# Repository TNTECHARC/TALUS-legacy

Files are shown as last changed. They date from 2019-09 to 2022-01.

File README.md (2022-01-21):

# Talus
Totally Autonomous Legitimately Useful System

***

## Languages
- API is coded in ArduinoIDE (basically C++)

***

## Spring 2022 Goals
- 3D print all missing body parts
- Get a full set of working servos
- Improve API functionality
  ### Stretch Goals
  - Work in inverse kinematics
  - Implement a Raspberry PI for servo and voice control

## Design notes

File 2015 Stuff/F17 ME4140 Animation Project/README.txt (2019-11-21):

Deliverables from a final project in the Fall 2017 session of Tennessee Tech
course ME 4140 Intro to Robotics. The goals were:
1. Develope an animation of TALUS using the concepts of forward and inverse
   kinematics (discussed both in ME 4140 and ME 3610 Dynamics of Machinery).
2. Further the development of TALUS hardware systems

This folder contains:
- stlread.m: a function which reads STLs into a MATLAB script
- TALUS_Forward_12_12_17: an unfinished program to complete Goal 1
- TALUS_Forward_12_12_17_demo: the script used to generate the
  following animations.
- Joint_animation: MP4 showing full range of motion for several joints
- Wave_animation: MP4 demonstrating a wave
- TALUS_Dem: an arduino code used to replicate the animate motions on the real robot
- Joint_demo: video of hardware system replicating corresponding animation
- Wave_demo: video of hardware system replicating corresponding animation

Also included are STLs of each rigid body on TALUS made by assembling the
individual part STLs found on the websites. This process required loading them
into Inventor with Mesh Enabler.

This project is by no means complete, as only a portion of the right arm is
functional (F2017). Reccomended future work includes completing forward kinematics for
the full body, verifying inverse kinematics, and working on path planning
concepts.

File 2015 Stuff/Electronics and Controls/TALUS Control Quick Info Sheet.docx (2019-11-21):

Servo Pins

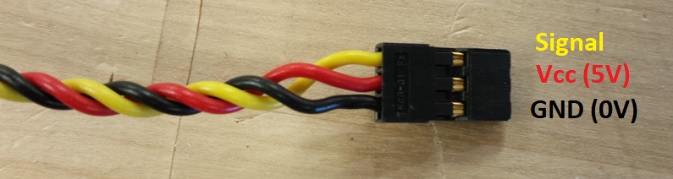
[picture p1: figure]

-Unaltered Servo Control Loop

-Altered Servo Control Loop

Arduino Code

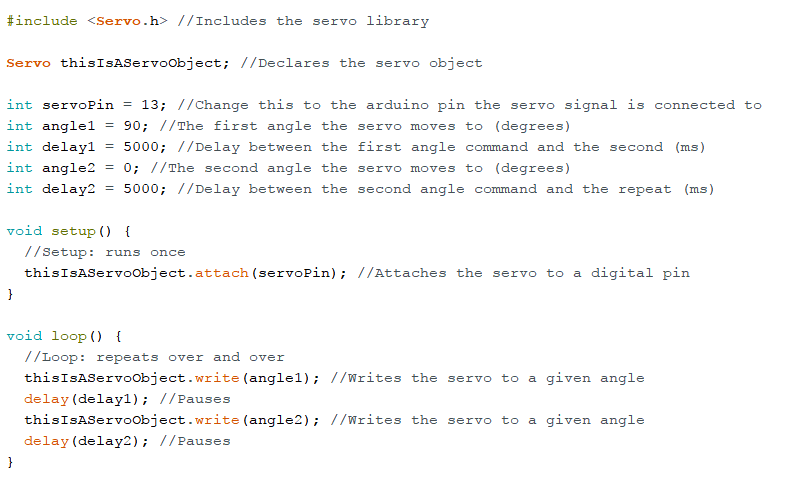
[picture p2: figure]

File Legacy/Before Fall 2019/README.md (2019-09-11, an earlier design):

# Overview
This is short documentation put together at the beginning of the fall 2019 semester. Documentation before this point does not exist.

# Wiring
Wiring for Talus using the arduino is described in the Wiring Layout.xlsx

Photos of the wiring from several angles are in the "Photos of Wiring" folder.

# Demonstration Documentation
All written notes of Talus operation is in Documentation.txt

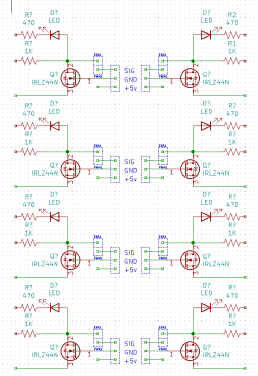
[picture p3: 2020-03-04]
Hardware/Schmatics/8 servo control board.png

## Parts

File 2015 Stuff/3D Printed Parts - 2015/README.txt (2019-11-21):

Parts 3D printed and used to build TALUS

Downloaded from the InMoov website

Created in 2015, may be useful as reference

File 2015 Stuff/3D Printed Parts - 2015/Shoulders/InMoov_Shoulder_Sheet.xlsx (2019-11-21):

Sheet: Sheet2
Right Shoulder
Body Part | File Name | # Required | # Printed | Sign-In | Sign- Out | Sign-In 2 | Sign-Out 2
Shoulder | PistonbaseV6 | 1 | 1 | 11:00:00 | 1:58:00
Shoulder | PistonClaviV3 | 1 |  | 9:10:00
Shoulder | PivConnectorV1 | 2 | 2 | ------- | ---------------- | ---------- | --------
Shoulder | PivGearV4 | 1 |  | 8:50:00 | ------
Shoulder | PivPotentioV2 | 1 |  | 8:50:00 | -----
Shoulder | PivWormV2 | 1 |  | 8:50:00 | -----
Shoulder | servoholsterV1 | 1 |  | Friedman
Shoulder | servoholderV1 | 2 |  | 8:50:00 | ----
Shoulder | PivcenterV1 | 1 | 1 | -------- | 8:20:00
Shoulder | PivMitV1 | 1 | 1 | 8:30:00 | Davies
Shoulder | PivPotholderV2 | 1 | 1 | Lam | Lam
Shoulder | PivTitV1 | 1 | 1 | 8:30:00 | Davies

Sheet: Sheet1
Left Shoulder
Body Part | File Name | # Required | # Printed | Sign-In | Sign- Out | Sign-In 2 | Sign-Out 2
Shoulder | PistonbaseV6 | 1 |  | Friedman | Lam
Shoulder | PistonClaviV3 | 1 |  | Lam | Lam
Shoulder | PivConnectorV1 | 2 |  | Lam | Lam | Lam | Lam
Shoulder | PivGearV3 | 1 |  | Ponder | Ponder
Shoulder | PivPotentioV2 | 1 |  | Lam | Lam
Shoulder | PivWormV2 | 1 |  | Lam | Lam
Shoulder | servoholsterV1 | 1 |  | Lam | Lam
Shoulder | servoholderV1 | 2 |  | Friedman | Lam | Friedman | Lam
Shoulder | leftPivcenterV1 | 1 |  | Davies | Davies
Shoulder | leftPivMitV1 | 1 |  | Davies | Ponder
Shoulder | leftPivPotholderV2 | 1 |  | Friedman | Lam
Shoulder | leftPivTitV1 | 1 |  | Davies | -----

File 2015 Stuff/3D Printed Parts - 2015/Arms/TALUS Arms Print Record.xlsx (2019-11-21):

body Part | file name | # required | # printed | sign in | sign out | sign out
left bicep | armtopcover1* | 1 |  | Hardyman
left bicep | armtopcover2* | 1
left bicep | armtopcover3* | 1
left bicep | elbowshaftgearV1 | 1 | 1 | ----- | ----- | -----
left bicep | GearHolderV1 | 1 | 1 | Friedman | Friedman
left bicep | gearpotentioV1* | 1 | 1 | Davies | Davies
left bicep | HighArmSideV2 | 2 | 2 | Harvey | ----- | -----
left bicep | leftRotcenterV2 | 1 | 1 | Friedman | Friedman
left bicep | leftRotTitV2 | 1 | 1 | Friedman | Friedman
left bicep | lowarmsideV1 | 2 | 2 | ----- | ----- | -----
left bicep | PistonanticlockV2* | 1 |  | Friedman
left bicep | PistonbaseantiV2* | 1 | 1 | Davies | Friedman
left bicep | reinforcerV1* | 2 | 2 | Friedman | Friedman | Friedman
left bicep | servobaseV1* | 1 | 1 | Davies | Davies
left bicep | servoholderV1* | 1 | 1 | Friedman | Friedman
left bicep | spacerV1 | 1 | 1 | Friedman | Friedman
left bicep | RotGearV4* | 1 | 1 | Davies | Davies
left bicep | RotMitV2 | 1 | 1 | Friedman | Friedman
left bicep | RotPotentioV2* | 1 | 1 | Davies | Davies
left bicep | RotWormV5* | 1 | 1 | Davies | Davies
right bicep | armtopcover2* | 1
right bicep | elbowshaftgearV1 | 1 | 1 | ----- | -----
right bicep | GearHolderV1 | 1 | 1 | Friedman | Friedman
right bicep | gearpotentioV1* | 1 | 1 | Davies | Davies
right bicep | HighArmSideV2 | 2 | 1 | Friedman | Friedman
right bicep | RotcenterV2 | 1 | 1 | Friedman | Friedman
right bicep | RotTitV2 | 1 | 1 | Friedman | Friedman
right bicep | lowarmsideV1 | 2 | 2 | Friedman | Friedman | Friedman
right bicep | PistonanticlockV2* | 1 |  | Friedman
right bicep | PistonbaseantiV2* | 1 | 1 | Davies | Friedman
right bicep | reinforcerV1* | 2 | 2 | Friedman | Friedman
right bicep | servobaseV1* | 1 | 1 | Friedman | Friedman
right bicep | servoholderV1* | 1 | 1 | Davies | Davies
right bicep | spacerV1 | 1 | 1 | Friedman | Friedman
left bicep | RotGearV4* | 1 | 1 | Davies | Davies
left bicep | RotMitV2 | 1 | 1 | Friedman | Friedman
left bicep | RotPotentioV2* | 1 | 1 | Davies | Davies
left bicep | RotWormV5* | 1 | 1 | Davies | Davies
*low priority

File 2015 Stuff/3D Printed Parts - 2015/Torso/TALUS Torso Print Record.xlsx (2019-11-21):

Body Part | File Name | # Required | # Printed | Sign-in | Sign-out | Sign-in 2 | Sign-out 2
Torso | homplateback-V1.stl | 1 | 1 | ------ | ------
Torso | homplateback+V1.stl | 1 | 1 | ------ | ------
Torso | homplatebacklow-V1.stl | 1 | 1 | 9:00:00 | 1:29:00
Torso | homplatebacklow+V1.stl | 1 | 1 | 9:00:00 | 1:29:00
Torso | homplatefront-V1.stl | 1 | 1 | 1:35:00 | 4:30:00
Torso | homplatefront+V1.stl | 1 | 1 | 1:35:00 | 4:30:00
Torso | servoHolsterV1.stl | 1 | 1 | ------ | ------
Torso | SternumV1.stl | 1 | 1 | ------ | -------
Torso | ThroatLowerV1.stl | 2 | 2 | ------- | ------ | ----- | ------
Torso | interkinectMidV1 | 2 | 2 | 15:34:00 | --- | 12:30:00 | 7:30:00
Torso | interkinectSideV1 | 2 | 2 | ------- | -----
Torso | KinectMidBackV1 | 1 | 1 | -------- | ------
Torso | KinectMidFrontV1 | 1 | 1 | ------- | -------
Torso | KinectSideBackV1 | 2 | 2 | ------- | -------
Torso | NeckV1 | 1 | 1 | 4:01:00 | 9:22:00
Torso | ThroatHolderV1 | 1 | 1 | 7:31:00 | 9:32:00
Torso | ThroatHoleV2 | 1 | 1 | 8:13:00 | 9:32:00
Torso | ClaviFrontV2 | 2 | 2 | 18:15:00 | ---- | ----- | -----
Torso | ClaviBackV2 | 2 | 2 | 9:01:00 | 3:02:00 | 9:01:00 | 3:02:00
Torso | BatteryHolderRightV1 | 1 | 1 | 6:00:00 | 9:32:00
Torso | BatteryHolderLeftV1 | 1 | 1 | 12:30:00 | 7:30:00
Torso | HomLowBackV1 | 2 | 2 | --------- | 8:00:00 | 2:50:00 | 1:00:00
Torso | ChestLowV1 | 2 | 2 | ---------- | ------- | --------- | ---------
Torso | Homelowfront | 2 | 2 | ------- | ------ | 1:22:00 | 9:28:00
Torso
Torso
Torso
Torso
Torso
 | *=couldn't find exact filename

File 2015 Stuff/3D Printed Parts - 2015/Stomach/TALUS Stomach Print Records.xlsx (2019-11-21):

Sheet: Sheet1
PART | NAME | QUANTITY | CHECK-IN | CHECK-OUT | CHECK-IN 2 | CHECK-OUT 2 | CHECK-IN 3 | CHECK-OUT 3 | CHECK-IN 4 | CHECK-OUT 4
TOP STMCH | DiskExternV2 | 4 | DAVIES | Davies | DAVIES | Davies | Davies | Davies | Davies | Davies
TOP STMCH | DiskExternV3 | 1 | Michael | Michael
TOP STMCH | DiskUnderV1 | 1 | Davies | Hill
TOP STMCH | RollBackLeftV1 | 1 | Davies | Davies
TOP STMCH | RollBackRightV1 | 1 | Michael
TOP STMCH | RollFrontLeftV1 | 1 | Davies | Davies
TOP STMCH | ServoBackV1 | 1 | Michael | Michael
TOP STMCH | StoGearAttachV1 | 1 | Davies | Davies
TOP STMCH | StomGearV2 | 1 | Davies | Davies
TOP STMCH | TStoBackLeftV1 | 1 | Davies | Davies
TOP STMCH | TStoBackRightV1 | 1 | Davies | Davies
TOP STMCH | TStoBackStandLeftV1 | 1 | Davies | Davies
TOP STMCH | TStobackStandRightV1 | 1 | Davies | Davies
TOP STMCH | TStoFrontLeftV1 | 1 | Friedman | Davies
TOP STMCH | TStoFrontRightV1 | 1 | Davies | Davies
TOP STMCH | TStoFrontStandLeftV1 | 1 | Davies | Davies
TOP STMCH | TStoFrontStandRightV1 | 1 | Davies | Davies
TOP STMCH | TStoFrontStandV2 | 1 | Davies | Davies
TOP STMCH | TStoMiddleV1 | 2 | Davies | Davies | Michael | Michael
TOP STMCH | TstoPistonLeftV2 | 1 | Michael | Michael
TOP STMCH | TStoPistonRightV2 | 1 | Michael | Michael
TOP STMCH | TStoServoHolsterV2 | 1 | Michael | Michael
TOP STMCH | TStomCovLeftV2 | 1 | Michael | Michael
TOP STMCH | TStomCovRightV2 | 1 | Michael | Michael
TOP STMCH | TStomPotHolderv1 | 1 | Michael | Michael
TOP STMCH | TStomRotBackV1 | 1 | Michael | Davies
TOP STMCH | TStomRotFrontV1 | 1 | Davies | Michael
TOP STMCH | TStomSpacerV1 | 1 | Davies | Michael
PRINT AT: 35% INFILL, 0.15 LAYER HEIGHT, 4 SHELLS

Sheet: Sheet2
Part | Name | Quantity | Check-in | Check-out | Check-in2 | Check-out2
Mid Stomach | BotBackLeftV1 | 1
Mid Stomach | BotBackRightV1 | 1
Mid Stomach | BotCapLeftV1 | 1
Mid Stomach | BotCapRightV1 | 1
Mid Stomach | BotFrontLeftV1 | 1
Mid Stomach | BotFrontRightv1 | 1
Mid Stomach | HipCoverFrontV1 | 1
Mid Stomach | HipCoverLeftV1 | 1
Mid Stomach | HipCoverRightV1 | 1 | Michael | Davies
Mid Stomach | MidPotHolderV1 | 1
Mid Stomach | MidWormRightV1 | 2

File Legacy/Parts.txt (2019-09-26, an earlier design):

MG996R
HS805bb
Raspberry Pi 3B+
PCA9685
--Unidentified 30A 5V Power Supply--

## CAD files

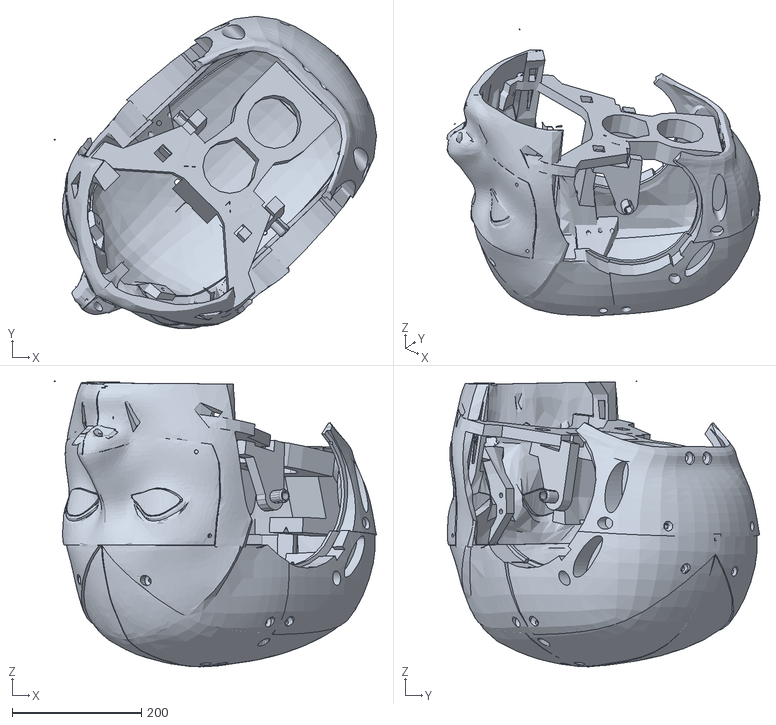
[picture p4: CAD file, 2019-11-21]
2015 Stuff/F17 ME4140 Animation Project/Matlab Code and Rigid-Body STLS/Face Assembly.stl
498.8 x 484.1 x 442.5

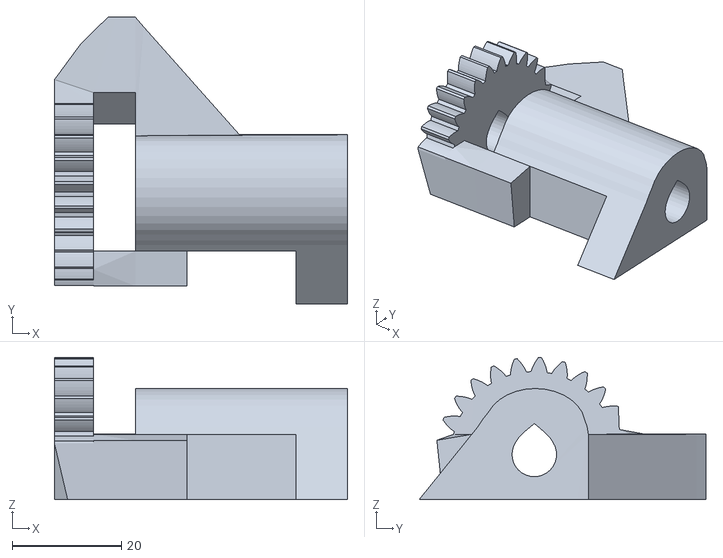
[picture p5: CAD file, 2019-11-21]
2015 Stuff/3D Printed Parts - 2015/Arms/elbowshaftgearV1.stl
53.5 x 52.4 x 26.0

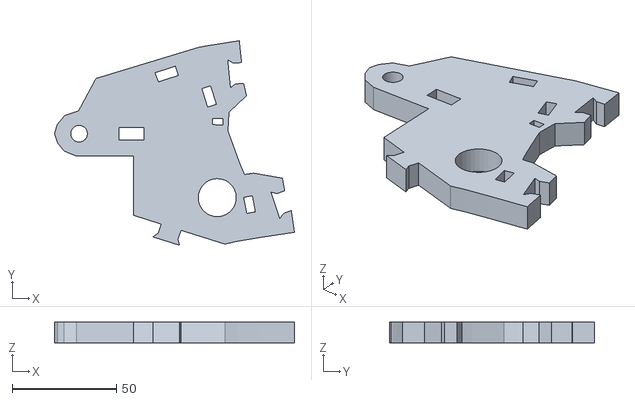
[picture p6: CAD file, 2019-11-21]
2015 Stuff/3D Printed Parts - 2015/Shoulders/Left Shoulder/ClaviBackV2.stl
114.9 x 97.9 x 10.0

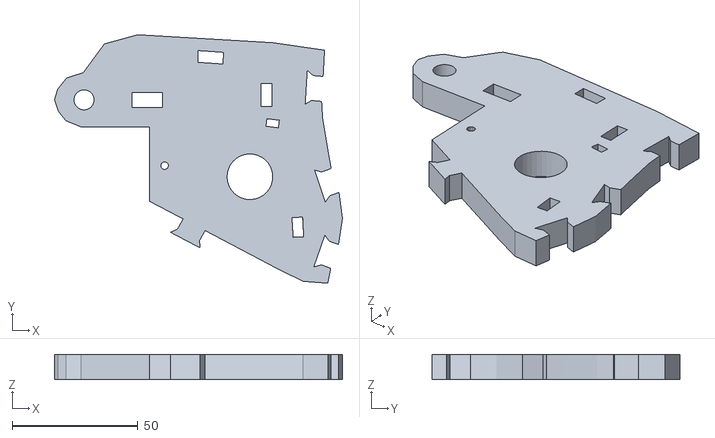
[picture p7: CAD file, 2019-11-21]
2015 Stuff/3D Printed Parts - 2015/Shoulders/Right Shoulder/ClaviFrontV2.stl
114.7 x 98.9 x 10.0

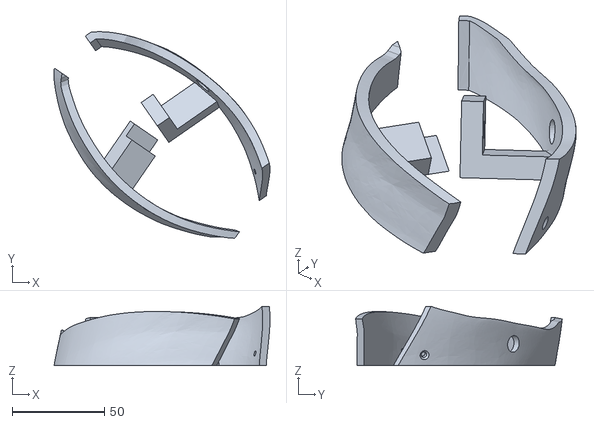
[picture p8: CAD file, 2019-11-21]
2015 Stuff/3D Printed Parts - 2015/Stomach/HipCoverRightV1.stl
116.8 x 111.7 x 32.1

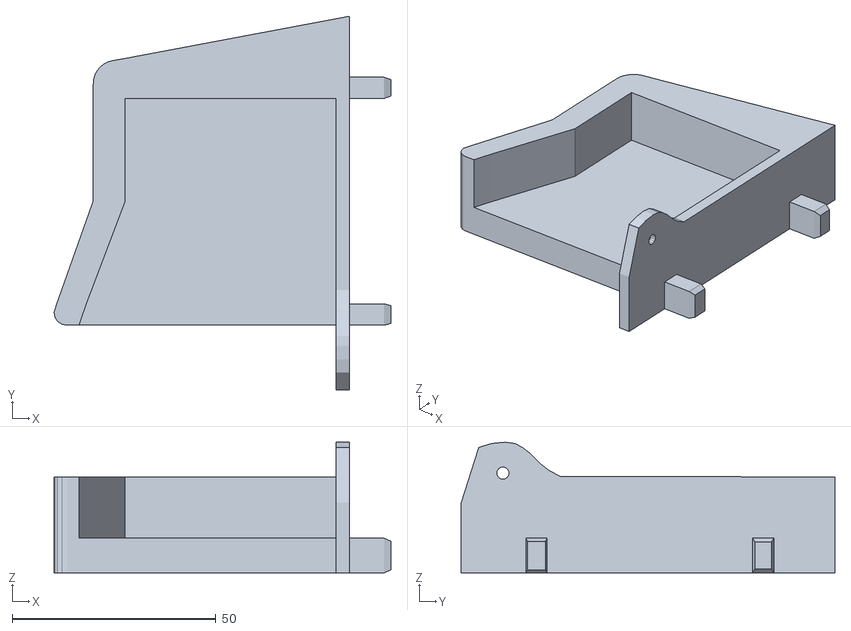
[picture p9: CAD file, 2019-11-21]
2015 Stuff/3D Printed Parts - 2015/Torso/BatteryHolderRightV1.stl
82.8 x 91.7 x 32.1

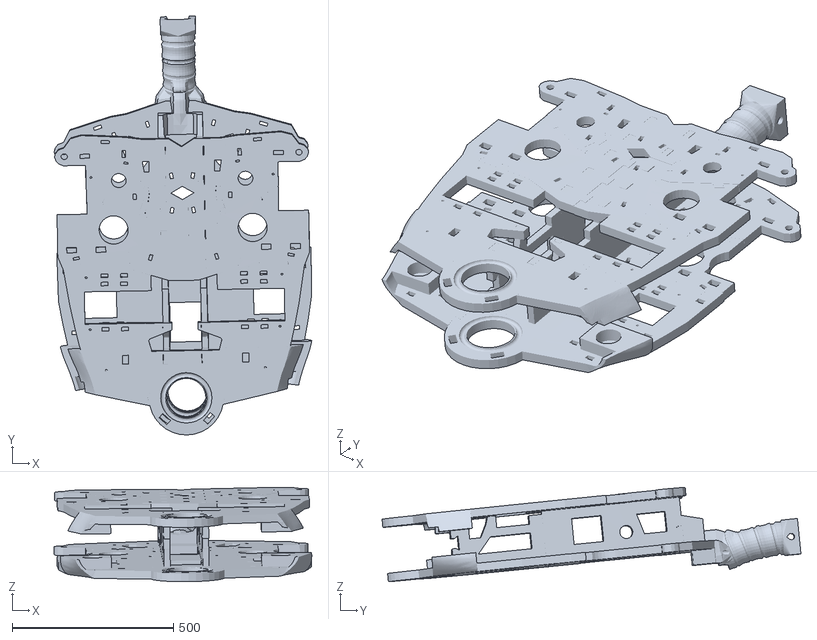
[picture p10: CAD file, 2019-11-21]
2015 Stuff/F17 ME4140 Animation Project/Matlab Code and Rigid-Body STLS/Torso.stl
799.5 x 1300.1 x 293.0

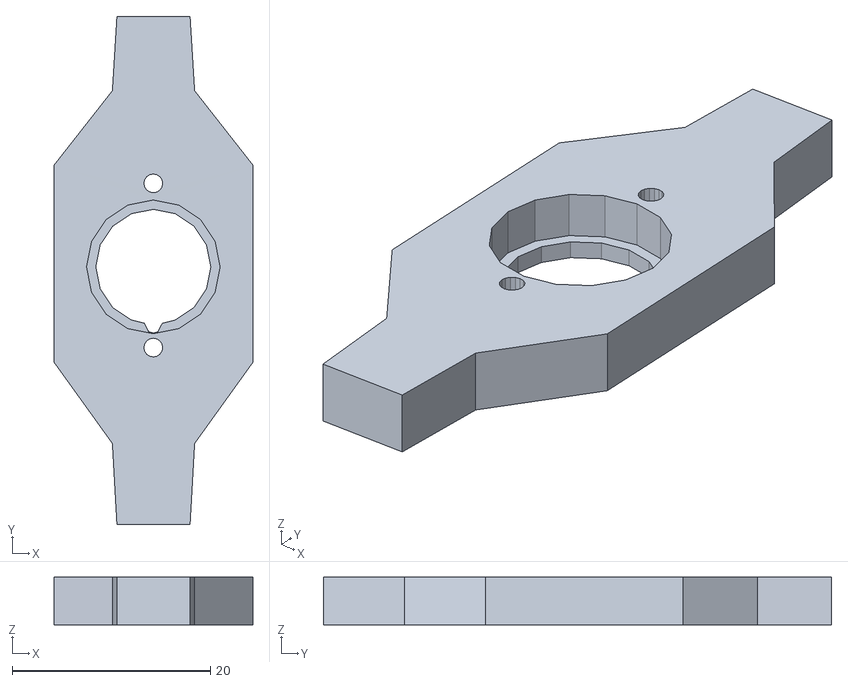
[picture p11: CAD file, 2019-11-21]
2015 Stuff/3D Printed Parts - 2015/Arms/RotPotentioV2.stl
20.1 x 51.3 x 4.83

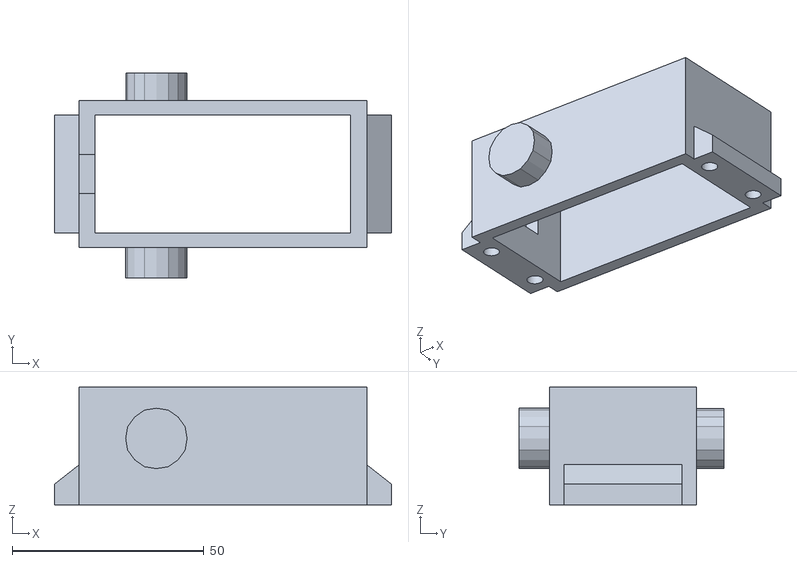
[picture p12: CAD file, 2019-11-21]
2015 Stuff/3D Printed Parts - 2015/Shoulders/Left Shoulder/servoHolsterV1.stl
87.9 x 53.5 x 30.7

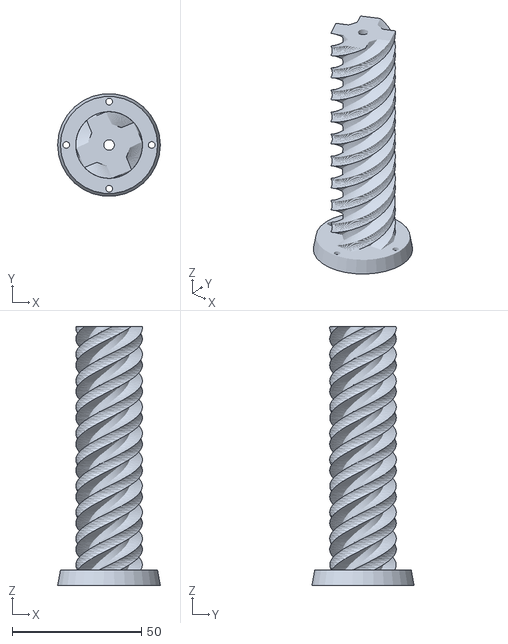
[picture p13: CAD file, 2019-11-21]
2015 Stuff/3D Printed Parts - 2015/Shoulders/Right Shoulder/PistonClaviV3.stl
39.7 x 39.5 x 100.1

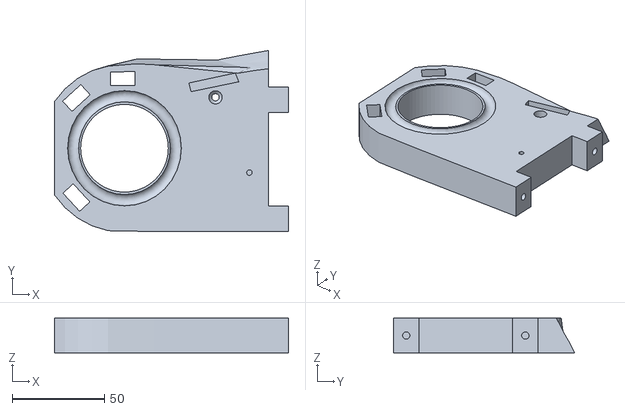
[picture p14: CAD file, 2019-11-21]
2015 Stuff/3D Printed Parts - 2015/Stomach/TStoLowLeftV1.stl
127.1 x 98.4 x 18.9

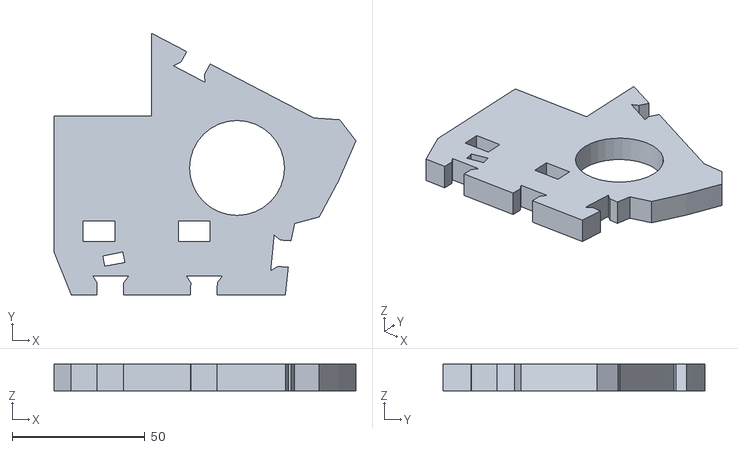
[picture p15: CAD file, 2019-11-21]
2015 Stuff/3D Printed Parts - 2015/Torso/HomLowFront-V1.stl
113.5 x 98.4 x 10.1

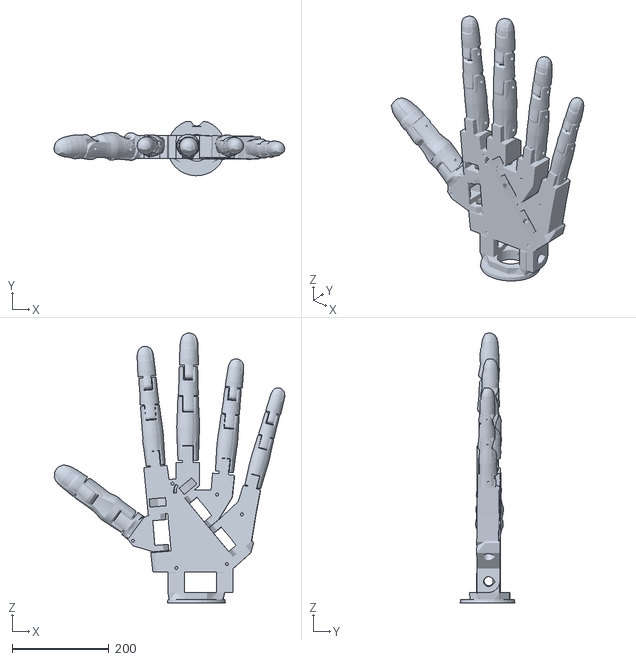
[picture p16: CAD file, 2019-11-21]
2015 Stuff/F17 ME4140 Animation Project/Matlab Code and Rigid-Body STLS/Right_Hand.stl
476.6 x 112.8 x 558.0

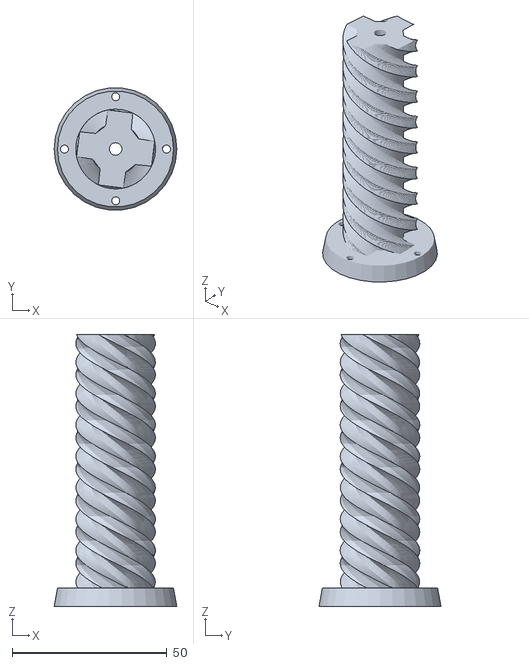
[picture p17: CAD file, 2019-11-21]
2015 Stuff/3D Printed Parts - 2015/Arms/PistonanticlockV2.stl
39.7 x 39.5 x 88.0

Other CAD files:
2015 Stuff/3D Printed Parts - 2015/Shoulders/Left Shoulder/leftPivcenterV1.stl
2015 Stuff/3D Printed Parts - 2015/Shoulders/Right Shoulder/PivcenterV1.stl
2015 Stuff/3D Printed Parts - 2015/Stomach/StomSupportRightV1.stl
2015 Stuff/3D Printed Parts - 2015/Arms/GearHolderV1.stl
2015 Stuff/3D Printed Parts - 2015/Arms/HighArmSideV2.stl
2015 Stuff/3D Printed Parts - 2015/Arms/PistonbaseantiV2.stl
2015 Stuff/3D Printed Parts - 2015/Arms/RotGearV4.stl
2015 Stuff/3D Printed Parts - 2015/Arms/RotMitV2.stl
2015 Stuff/3D Printed Parts - 2015/Arms/RotTitV2.stl
2015 Stuff/3D Printed Parts - 2015/Arms/RotWormV5.stl
2015 Stuff/3D Printed Parts - 2015/Arms/RotcenterV2.stl
2015 Stuff/3D Printed Parts - 2015/Arms/armtopcover1.stl
2015 Stuff/3D Printed Parts - 2015/Arms/armtopcover2.stl
2015 Stuff/3D Printed Parts - 2015/Arms/armtopcover3.stl
2015 Stuff/3D Printed Parts - 2015/Arms/gearpotentioV1.stl
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

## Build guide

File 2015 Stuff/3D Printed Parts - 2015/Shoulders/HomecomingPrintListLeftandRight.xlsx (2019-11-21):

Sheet: Sheet1
Homecoming Print List- Left | Sign In | Sign Out
Priority
GearHolderV1 | Friedman | Friedman
RotGearV4 | Davies | Davies
RotWormV5 | Davies
GearPotentioV1 | Davies
Print after R&L Priority parts are done
ServoBaseV1-Extra
ServoHolderV1-Extra

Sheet: Sheet2
Homecoming Print List- Right | Sign In | Sign Out
Priority
GearHolderV1 | Friedman | Friedman
RotGearV4 | Hardyman | Davies
RotWormV5 | Davies
GearPotentioV1 | Davies
Print after R&L Priority parts are done
ServoBaseV1-Extra
ServoHolderV1-Extra
0

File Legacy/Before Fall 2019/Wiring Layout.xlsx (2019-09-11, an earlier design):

General Info | Control Buttons |  |  | Servos
MainBoard Used: Arduino Mega 1280 | Cable # | Color of Cable | Port | Color | Port(s)
Button Board is not mapped, but is still in one piece | 1 | Tan/Peach | D30 | Blue | GND
All PWM cables go to the White or Tan/Peach lead of servos | 1 | Red | D22 | Red | 5v
D stands for Digital | 1 | Brown | Reset | Yellow | PWM 2-6
 | 2 | Black | D23 | Orange | PWM 7-8
 | 2 | White | D32 | Green | PWM 10-11
 | 2 | Gray | D24 | White | PWM 12
 | 2 | Purple | GND | Tan/Peach | PWM 13
 | 2 | Blue | D33
 | 2 | Green | D25
 | 2 | Yellow | D34
 | 2 | Tan/Peach | D26
 | 2 | Red | D35
 | 2 | Brown | D27

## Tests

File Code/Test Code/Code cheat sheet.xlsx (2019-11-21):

File name: | Version: | description:
Talus2.ino | 0.01 | program to test the hand of

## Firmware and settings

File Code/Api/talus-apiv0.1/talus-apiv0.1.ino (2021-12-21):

/*
 Name:		talus_apiv0.ino
 Created:	2/11/2020 3:09:44 PM
 Author:	Payton DePietro
*/
#include <Servo.h>
// the setup function runs once when you press reset or power the board

//setting
//max ammount of arguments
const int ARGSNUM = 5;
//creates argument storage location
String argArray[ARGSNUM + 1];

//temp variables
String tempString;
int servonum;
//function list
String functionList[] = {"enableAll","disableAll","enablePin","disablePin","setServo","handOpen","handClose","wingsUp","wave","default","setHand" };
//servo object
Servo servos[8];

void setup() {
	//serial set up and timeout adjustment for quicker response
	Serial.begin(9600);
	Serial.setTimeout(5);

	//setup all pins as outputs
	//with i and j there are two "for" loops running together
	int j = 0;
	for (int i = 22; i < 37;i++) {
		//prints some debug information
		Serial.println("Servo Pin: " + (String)i + " Enable Pin: " + (String)(i+1) + " RefPin: " + (String)j);
		//starts at the jth servo and links/attaches it with the ith pin , then sets it to 90 degrees
		servos[j].attach(i);
		servos[j].write(90);
		//increase j and i (i need to be incremented becuse the mosfet/enable pin and servo pin arent the same) 
		j++;
		i++;
		//sets up the mosfet/enable pin as output and enables it
		pinMode(i, OUTPUT);
		digitalWrite(i, HIGH);
	}
	//servo 5 - 7 have different default locations compared to all the other servos
	servos[5].write(150);
	servos[6].write(90);
	servos[7].write(90);
	Serial.println("end of setup!");
}


// main loop
void loop() {
	//checks if there is new data available on the serial line
	if (Serial.available()) {
		//if serial is available it then sends the string to the command parser
		commandParser(Serial.readString());
		//lists the current command and any args that go along with it
		for (int i = 0; i < ARGSNUM; i++) {
			Serial.println(argArray[i]);
		}
	}

	//stores the command number or 60 if the command is not valid
	int tempint = infinity;
	//takes the most current command and compares it to the function list array to see if there are any matches
	for (int i = 0; i < (sizeof(functionList) / sizeof(*functionList)); i++) {
		if (argArray[0] == functionList[i]) {
			tempint = i;
			//Review: possible reenable this exit to speed up the code -Payton DePietro
			//exit;
		}
	}
	// takes the command number from the above search and sends it to the approiate code
	switch (tempint) {
	case 0:
		//this is the enableAll command
		for (int i = 23; i < 38; i++) {
			servonum = (i - 22) / 2;
			digitalWrite(i, HIGH);
			i++;
		}
		break;
	case 1:
		//this is the disableAll command
		for (int i = 23; i < 38; i++) {
			servonum = (i - 22) / 2;
			digitalWrite(i, LOW);
			i++;
		}
		break;
	case 2:
		//this is the enablePin command
		//addresses the on board pin number
		digitalWrite(argArray[1].toInt(), HIGH);
		break;
	case 3:
		//this is the  disabelPin command
		//addresses the on board pin number
		digitalWrite(argArray[1].toInt(), LOW);
		break;
	case 4:
		//this is the setServo command
		// addressed by the servo num ie 0-7
		servonum = argArray[1].toInt();
		servos[servonum].write(argArray[2].toInt());
		break;
	case 5:
		//this is the handOpen command
		for (int i = 0; i < 5; i++) {
			servos[i].write(80);
		}
		break;
	case 6:
		//this is the handClose command
		for (int i = 0; i < 5; i++) {
			servos[i].write(0);
		}
		break;
	case 7 :
		//this is the wingsUp command
		servos[5].write(150);
		servos[0].write(90);
		servos[1].write(0);
		servos[2].write(0);
		servos[3].write(0);
		servos[4].write(90);
		break;
	case 8 :
		//this is the wave command
		//USE CAUTION WHEN USING
		servos[6].write(180);
		delay(500);
		for (int i = 0; i < 2; i++) {
			servos[5].write(160);
			delay(1000);
			servos[5].write(90);
			delay(1000);
		}
		servos[5].write(160);
		break;
	case 9 :
		//this is the default command
		servos[0].write(45);
		servos[1].write(45);
		servos[2].write(45);
		servos[3].write(45);
		servos[4].write(45);
		servos[5].write(150);
		servos[6].write(90);
		servos[7].write(90);
		break;
	case 10:
    // this is the setHand command
		servos[0].write(argArray[1].toInt());
		servos[1].write(argArray[2].toInt());
		servos[2].write(argArray[3].toInt());
		servos[3].write(argArray[4].toInt());
		servos[4].write(argArray[5].toInt());
		break;
	default:
		break;
	}
	//this makes the current command something not in the command list so when the loop restarts and there is no serial input it doesent keep running the same command
	argArray[0] = "billybobjoe";
}


//breaks down the input from serial into an array of all the arguments and the command itself
String * commandParser(String tempString){
	//variables for later use
	int j = 0;
	int beginArgs = 0;
	int endArgs = 0;
	//temp array to store the seperation potins between args
	int args[ARGSNUM + 2];
	// sets the start point of the args (has to be negative 1 for the math to work out later)
	//Review: make it so this -1 isnt here anymore -Payton DePietro
	args[j] = -1;
	j++;
	//loops throught all characters in the string being parsed, and looks for specific characters
	for (int i = 0; i < tempString.length(); i++) {
		//if the character is "(" this signafies the beging of the arguments and the end of the command
		if (tempString[i] == '(') {
			beginArgs = i;
			args[j] = i;
			j++;
		}
		//if the character is ")" this signafies the end of the arguments
		else if (tempString[i] == ')') {
			endArgs = i;
			args[j] = i;
			j++;
		}
		//searches for commas and saves there location in the args array
		else if (tempString[i] == ',') {
			if (j < ARGSNUM + 1) {
				args[j] = i;
				j++;
			}
		}
	}
	//goes throught all the save comma bracket and comma location and saves the string that is inbetween them for use in the code
	for (int i = 0; i < ARGSNUM+1; i++) {
		argArray[i] = tempString.substring(args[i] + 1, args[i + 1]);
	}
	return argArray;
}

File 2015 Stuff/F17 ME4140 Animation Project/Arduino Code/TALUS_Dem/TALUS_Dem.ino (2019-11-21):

#include <Servo.h> //Includes the servo library

int jointPin = 2;
int wavePin = 3;
int led = 4;

Servo Hip; Servo ShldrPiv; Servo ShldrRot; Servo ShldrSpn;
int hpin = 6; int ppin = 9; int rpin = 10; int spin = 11;
int hPos[6] = {0,1.5,180,1.5,90,1.5}; //0: left, 180: right
int pPos[4] = {180,1.5,0,1.5}; //0: down, 180: up
int rPos[4] = {110,6,20,6}; //0: back, 110: ahead, 20: straight down
int sPos[4] = {135,5.5,45,5.5};

void DemoJointMotions();
void ZeroPos();
void Wave();


void setup() {
  pinMode(jointPin,INPUT);
  pinMode(wavePin,INPUT);
  pinMode(led,OUTPUT);
  digitalWrite(led,HIGH);
  
  Hip.attach(hpin);
  ShldrPiv.attach(ppin);
  ShldrRot.attach(rpin);
  ShldrSpn.attach(spin);
  
  ZeroPos();
  delay(5000);
}

void loop() {
 if(!digitalRead(jointPin)) {
  DemoJointMotions();
 }
 else if(!digitalRead(wavePin)) {
  Wave();
 }
 delay(2000);
}

void ZeroPos() {
  Hip.write(hPos[4]);
  ShldrPiv.write(pPos[2]);
  ShldrRot.write(rPos[2]);
  ShldrSpn.write(sPos[2]);
}

void DemoJointMotions() {
  Hip.write(hPos[0]);delay(1000*hPos[1]);
  Hip.write(hPos[2]);delay(1000*hPos[3]);
  Hip.write(hPos[4]);delay(1000*hPos[5]);
  
  ShldrPiv.write(pPos[0]);delay(1000*pPos[1]);
  ShldrPiv.write(pPos[2]);delay(1000*pPos[3]);
  
  ShldrRot.write(rPos[0]);delay(1000*rPos[1]);
  ShldrSpn.write(sPos[0]);delay(1000*sPos[1]);
  ShldrSpn.write(sPos[2]);delay(1000*sPos[3]);
  ShldrRot.write(rPos[2]);delay(1000*rPos[3]);
}

void Wave() {
  Hip.write(0);ShldrPiv.write(0);ShldrRot.write(180);ShldrSpn.write(45);delay(12000);
  ShldrPiv.write(180);delay(1500);
  ShldrPiv.write(0);delay(1500);
  ShldrPiv.write(180);delay(1500);
  ShldrPiv.write(0);delay(1500);
  ShldrPiv.write(180);delay(1500);
  ShldrPiv.write(0);delay(1500);
  Hip.write(90);ShldrRot.write(20);delay(10000);
}

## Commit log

2019-09-11 Before Fall 2019 Setup Documentation
    [Wiring Layout.xlsx]
2019-11-21 reformated and organized
    [BatteryHolderLeftV1.stl, BatteryHolderRightV1.stl, BotBackLeftV1.stl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]
2020-03-04 Create 8 servo control board.png
2020-03-04 v0.1 api
    [Api-documentation.xlsx]
2021-11-12 talus api update
    [Api-documentation.xlsx]
2021-12-21 paytons last commit
    [Api-documentation.xlsx]
2022-01-27 i2c work v0.1
2022-01-27 i2c work v0.2
2022-01-27 i2c work v0.3
2022-01-27 i2c work v0.4
2022-01-27 i2c work v0.5
2022-01-27 i2c work v0.6
2022-02-22 i2c work v0.7
